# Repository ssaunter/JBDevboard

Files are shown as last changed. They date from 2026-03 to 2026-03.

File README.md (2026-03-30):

# JBDevboard
A custom RP2040 dev board utilizing a NCP1117 LDO. This project is a modified version of the RP2040 devboard project by [Kai Pereira](https://github.com/KaiPereira/build-a-devboard), which has served as a great resource for learning about devboard production. This board is essentially a clone of a Raspberry Pi RP2040 board.

Here is a look at the current build:

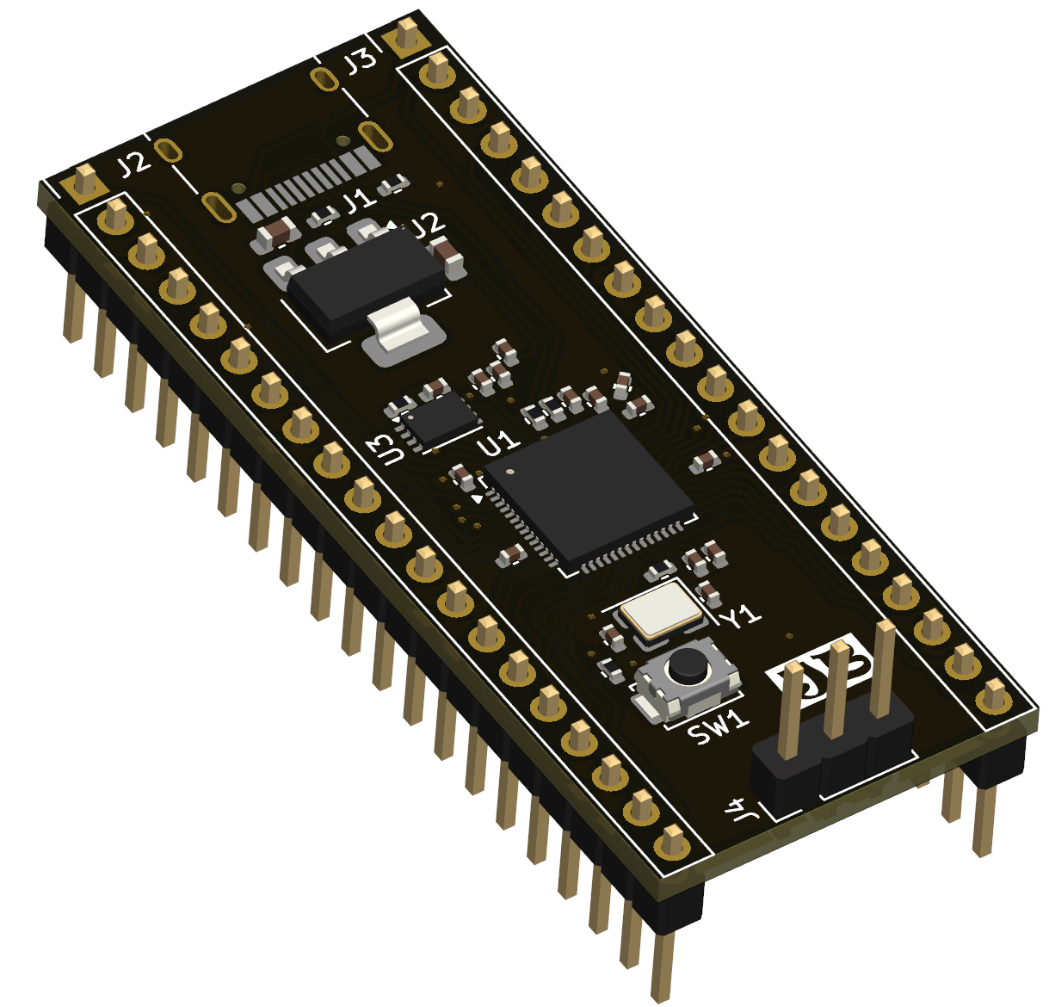
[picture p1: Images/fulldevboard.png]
First Design


The large IC near the back of the board, labeled U2, is the NCP1117. It is capable of providing an output current of 1.0 A, which is an upgrade from the LDOs in the tutorial, which has a max output current of 250 mA.

Here's the schematic:
---

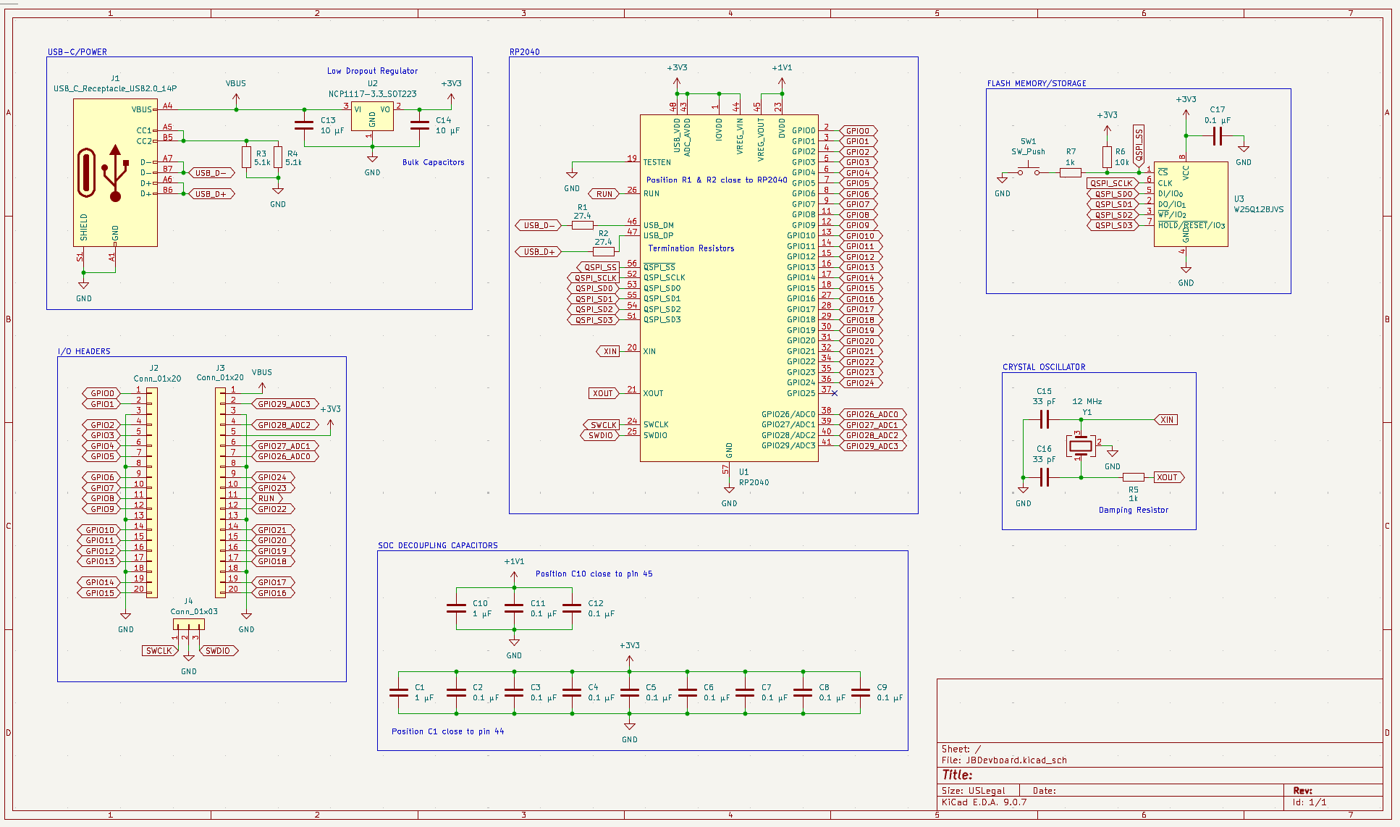
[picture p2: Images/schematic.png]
Schematic Design


And here's what the trace layers look like:
---

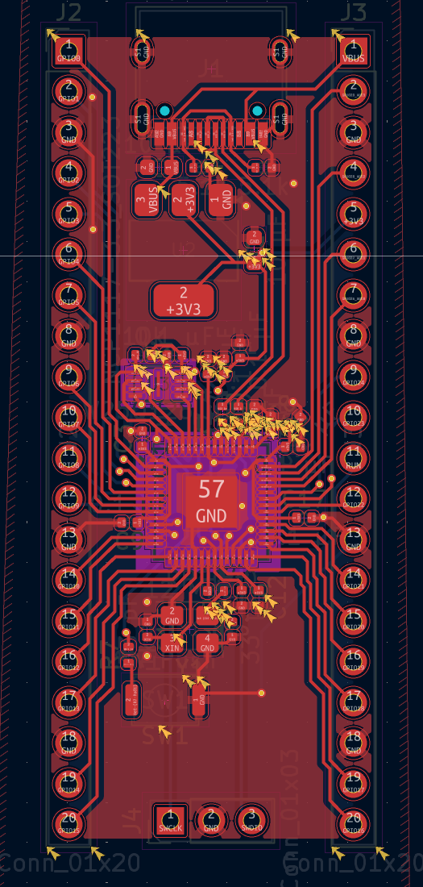
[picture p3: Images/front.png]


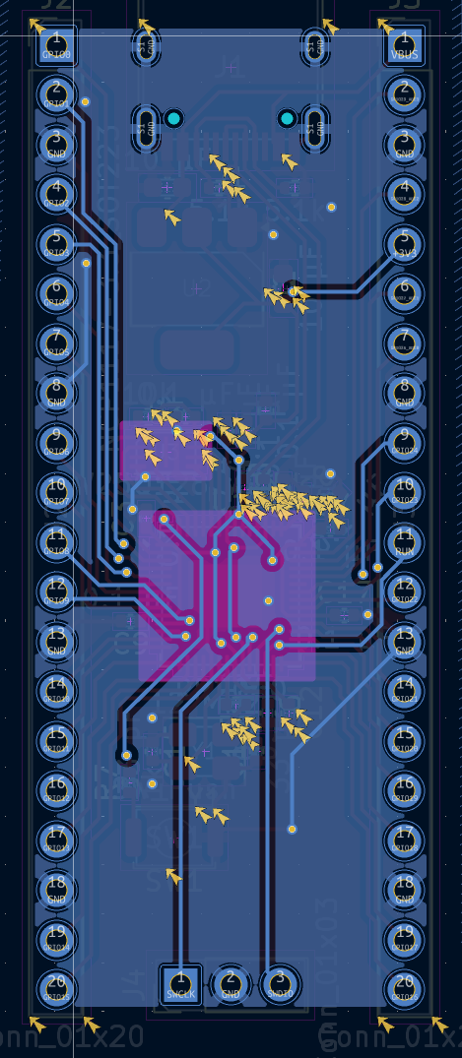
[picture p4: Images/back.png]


---
### Bill of Materials
---

| Part | Quantity | Price Per | Link | 
| :--- | :---: | :---: | :--- |
| **RP2040** | 1 | $0.70 | [DigiKey](https://www.digikey.com/short/ndb2782v) |
| **NCP1117** | 1 | $0.37 | [DigiKey](https://www.digikey.com/short/5j4t47bt) |
| **USB-C Recepticle** | 1 | $0.47 | [DigiKey](https://www.digikey.com/short/z2dbcnt0) |
| **W25Q128JVEIM TR** | 1 | $2.31 | [DigiKey](https://www.digikey.com/short/mfqznn09) |
| **12 Mhz Xtal Osc** | 1 | $1.35 | [DigiKey](https://www.digikey.com/short/h02qvddd) |
| **1x20 Header** | 2 | $0.50 |[DigiKey](https://www.digikey.com/short/dqz7fj2b) |
| **1x3 Header** | 1 | $0.17 | [DigiKey](https://www.digikey.com/short/td5n0hbf) |
| **5.1k R 0402** | 2 | $0.10 |[DigiKey](https://www.digikey.com/short/c9z4njr9) |
| **27.4 R 0402** | 2 | $0.10 |[DigiKey](https://www.digikey.com/short/pqdzv9nf) |
| **1k R 0402** | 2 | $0.10 | [DigiKey](https://www.digikey.com/short/ptpr3b5v) |
| **10k R 0402** | 1 | $0.10 |[DigiKey](https://www.digikey.com/short/1bqf9rrt) |
| **0.1uF C 0402** | 11 | $0.03 |[DigiKey](https://www.digikey.com/short/prnwd7b4) |
| **1uF C 0402** | 1 | $0.08 | [DigiKey](https://www.digikey.com/short/bh2hq3n5) |
| **33pF C 0402** | 2 | $0.10 |[DigiKey](https://www.digikey.com/short/87qt971h) |
| **10uF C 0603** | 2 | $0.47 |[DigiKey](https://www.digikey.com/short/22nm5zq0) |
| **Push Button** | 1 | $0.41 | [DigiKey](https://www.digikey.com/short/8bz14998) |
| **PCB** | 1 | $2.10 | [JCLPCB](https://jlcpcb.com/) |
| **PCB Stencil** | 1 | $7.11 | [JCLPCB](https://jlcpcb.com/) |
| **JLCPCB Tax + Shipping** |  | ~$20.31 | |
| **DigiKey Tax + Shipping** |  | ~$8.56 | 
| **TOTAL** |  | $46.12 |

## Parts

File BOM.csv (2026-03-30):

Part | Quantity | Price Per | Link
RP2040 | 1 | $0.70 | https://www.digikey.com/short/ndb2782v
NCP1117 | 1 | $0.37 | https://www.digikey.com/short/5j4t47bt
USB-C Recepticle | 1 | $0.47 | https://www.digikey.com/short/z2dbcnt0
W25Q128JVEIM TR | 1 | $2.31 | https://www.digikey.com/short/mfqznn09
12 Mhz Xtal Osc | 1 | $1.35 | https://www.digikey.com/short/h02qvddd
1x20 Header | 2 | $0.50 | https://www.digikey.com/short/dqz7fj2b
1x3 Header | 1 | $0.17 | https://www.digikey.com/short/td5n0hbf
5.1k R 0402 | 2 | $0.10 | https://www.digikey.com/short/c9z4njr9
27.4 R 0402 | 2 | $0.10 | https://www.digikey.com/short/pqdzv9nf
1k R 0402 | 2 | $0.10 | https://www.digikey.com/short/ptpr3b5v
10k R 0402 | 1 | $0.10 | https://www.digikey.com/short/1bqf9rrt
0.1uF C 0402 | 11 | $0.03 | https://www.digikey.com/short/prnwd7b4
1uF C 0402 | 1 | $0.08 | https://www.digikey.com/short/bh2hq3n5
33pF C 0402 | 2 | $0.10 | https://www.digikey.com/short/87qt971h
10uF C 0603 | 2 | $0.47 | https://www.digikey.com/short/22nm5zq0
Push Button | 1 | $0.41 | https://www.digikey.com/short/8bz14998
PCB | 1 | $2.10 | https://jlcpcb.com/
PCB Stencil | 1 | $7.11 | https://jlcpcb.com/
JLCPCB Tax + Shipping |  | ~$20.31
DigiKey Tax + Shipping |  | ~$8.56
TOTAL |  | $46.12

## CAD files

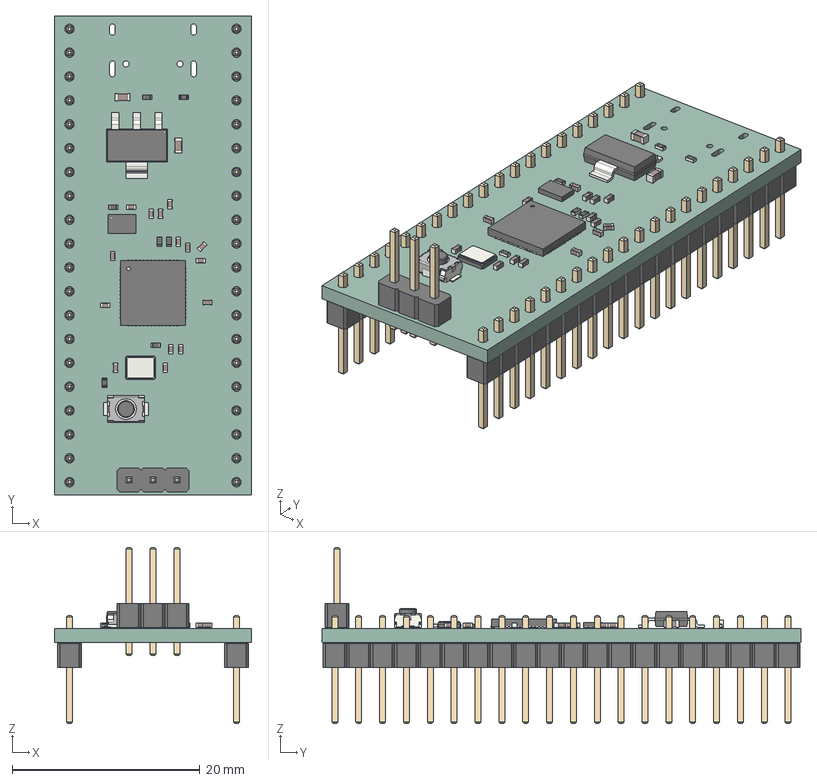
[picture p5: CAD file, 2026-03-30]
cad/JBDevboard.step
21.0 x 51.0 x 18.8 mm
R_0402_1005Metric x 7
PinHeader_1x03_P2.54mm_Vertical
C_0402_1005Metric x 15
SW_Push_SPST_NO_Alps_SKRK
C_0603_1608Metric x 2
QFN-56-1EP_7x7mm_P0.4mm_EP3.2x3.2mm
SOT-223
PinHeader_1x20_P2.54mm_Vertical x 2
Crystal_SMD_3225-4Pin_3.2x2.5mm
Winbond_USON-8-1EP_3x2mm_P0.5mm_EP0.2x1.6mm
JBDevboard_PCB

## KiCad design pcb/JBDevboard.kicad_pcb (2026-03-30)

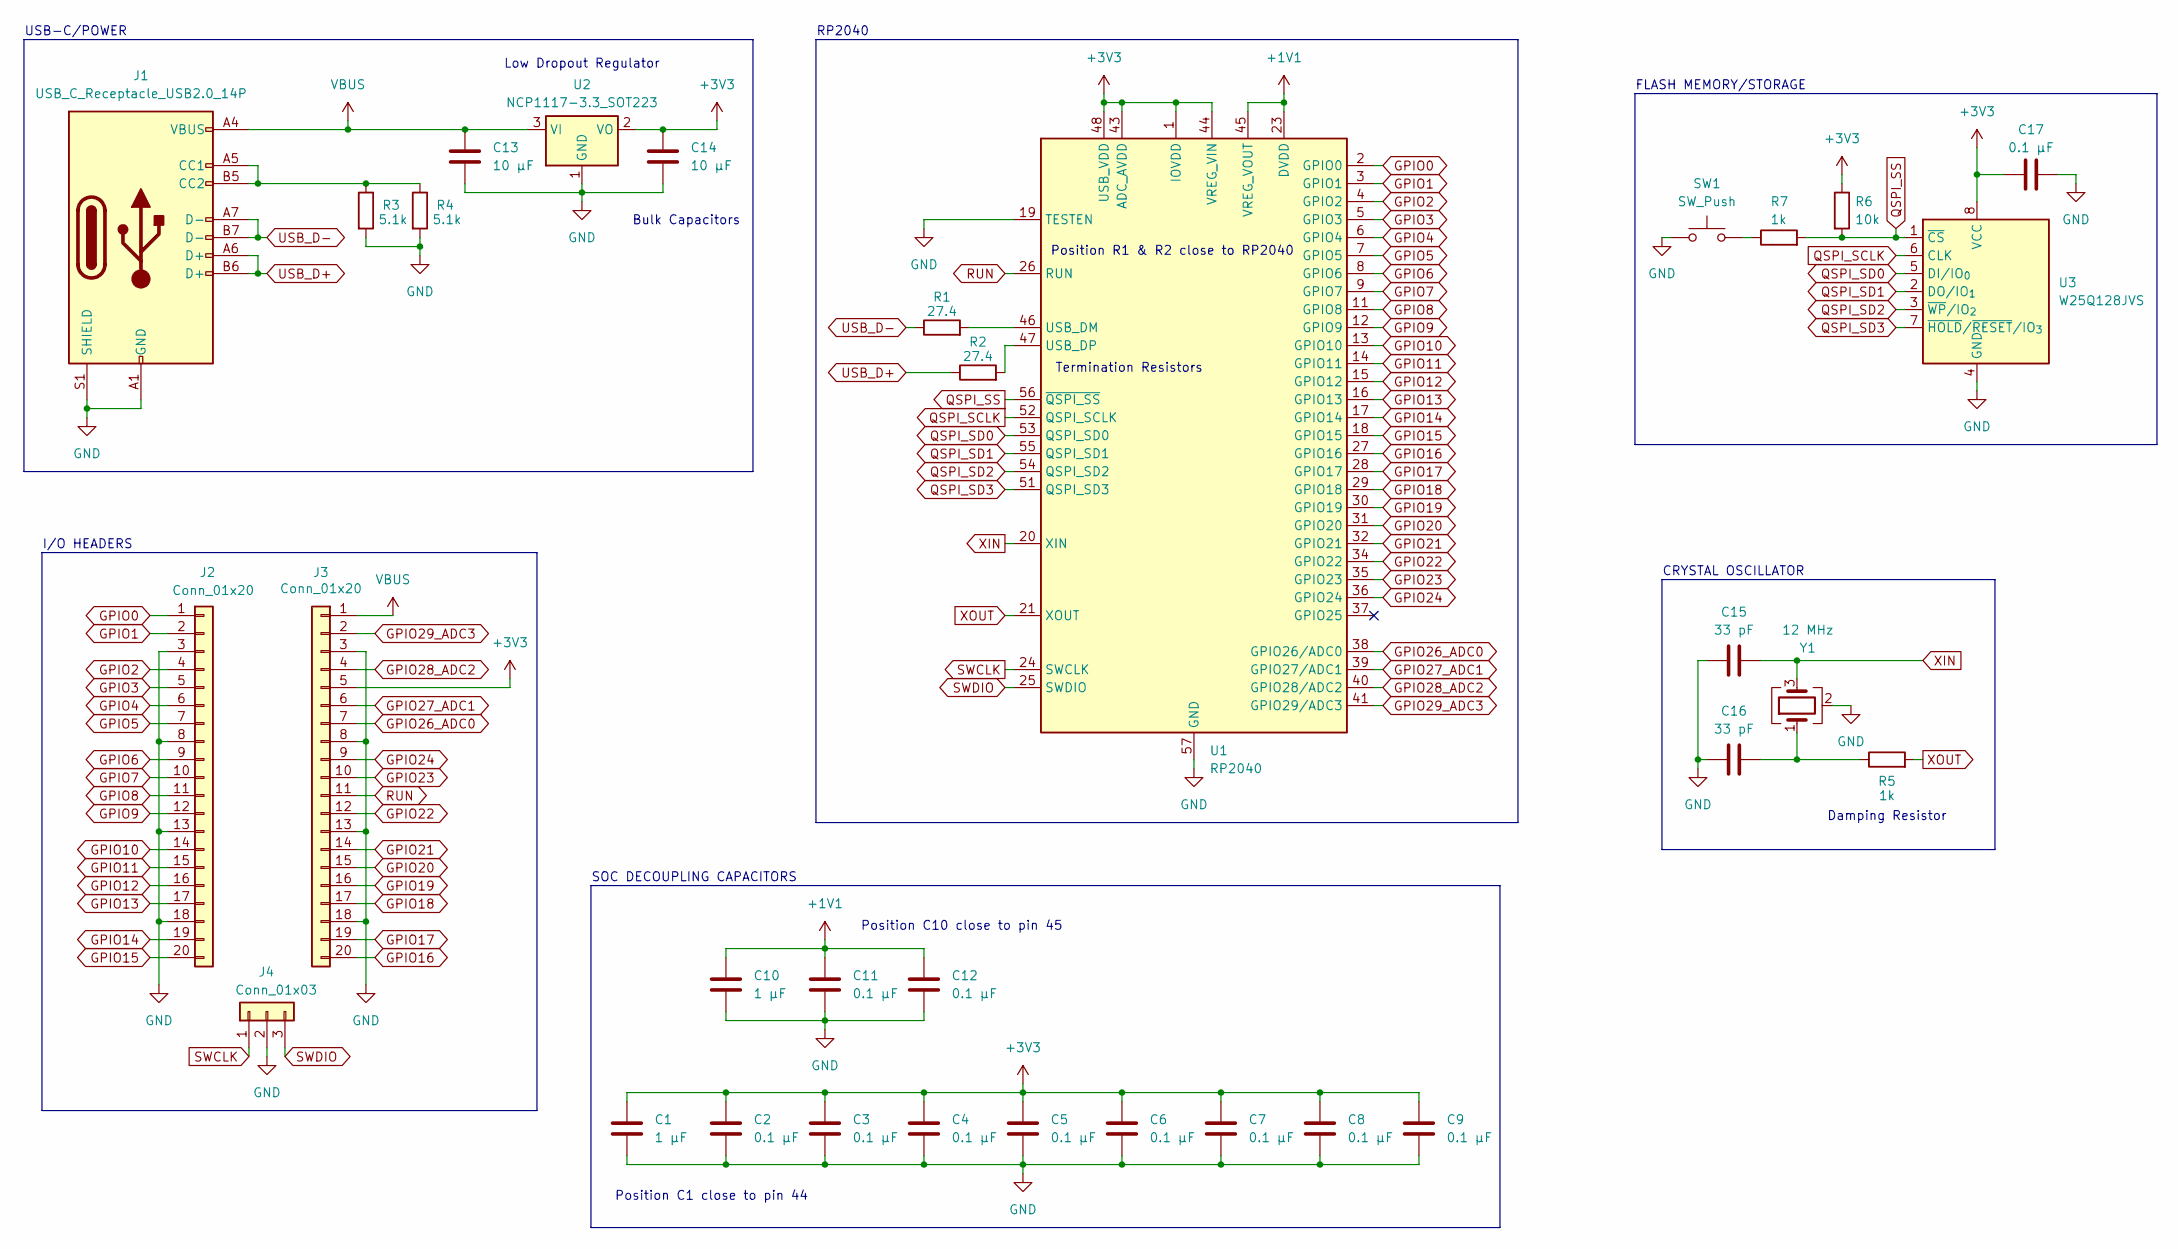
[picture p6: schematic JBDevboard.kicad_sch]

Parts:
C1, C10: 1 μF; C_0402_1005Metric
C2, C3, C4, C5, C6, C7, C8, C9, C11, C12, C17: 0.1 μF; C_0402_1005Metric
C13, C14: 10 μF; C_0603_1608Metric
C15, C16: 33 pF; C_0402_1005Metric
J1: USB_C_Receptacle_USB2.0_14P; USB_C_Receptacle_HRO_TYPE-C-31-M-12
J2, J3: Conn_01x20; PinHeader_1x20_P2.54mm_Vertical
J4: Conn_01x03; PinHeader_1x03_P2.54mm_Vertical
R1, R2: 27.4; R_0402_1005Metric
R3, R4: 5.1k; R_0402_1005Metric
R5, R7: 1k; R_0402_1005Metric
R6: 10k; R_0402_1005Metric
SW1: SW_Push; SW_Push_SPST_NO_Alps_SKRK
U1: RP2040; QFN-56-1EP_7x7mm_P0.4mm_EP3.2x3.2mm
U2: NCP1117-3.3_SOT223; SOT-223-3_TabPin2
U3: W25Q128JVS; Winbond_USON-8-1EP_3x2mm_P0.5mm_EP0.2x1.6mm
Y1: 12 MHz; Crystal_SMD_3225-4Pin_3.2x2.5mm

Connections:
+1V1: C10.1, C11.1, C12.1, U1.23 (DVDD), U1.45 (VREG_VOUT), U1.50 (DVDD)
+3V3: C1.1, C2.1, C3.1, C4.1, C5.1, C6.1, C7.1, C8.1, C9.1, C14.1, C17.1, J3.5, R6.1, U1.1 (IOVDD), U1.10 (IOVDD), U1.22 (IOVDD), U1.33 (IOVDD), U1.42 (IOVDD), U1.43 (ADC_AVDD), U1.44 (VREG_VIN), U1.48 (USB_VDD), U1.49 (IOVDD), U2.2 (VO), U3.8 (VCC)
GND: C1.2, C2.2, C3.2, C4.2, C5.2, C6.2, C7.2, C8.2, C9.2, C10.2, C11.2, C12.2, C13.2, C14.2, C15.1, C16.1, C17.2, J1.A1 (GND), J1.A12 (GND), J1.B1 (GND), J1.B12 (GND), J1.S1 (SHIELD), J2.3, J2.8, J2.13, J2.18, J3.3, J3.8, J3.13, J3.18, J4.2, R3.2, R4.2, SW1.1, U1.19 (TESTEN), U1.57 (GND), U2.1 (GND), U3.4 (GND), Y1.2 (G), Y1.4 (G)
GPIO0: J2.1, U1.2 (GPIO0)
GPIO1: J2.2, U1.3 (GPIO1)
GPIO2: J2.4, U1.4 (GPIO2)
GPIO3: J2.5, U1.5 (GPIO3)
GPIO4: J2.6, U1.6 (GPIO4)
GPIO5: J2.7, U1.7 (GPIO5)
GPIO6: J2.9, U1.8 (GPIO6)
GPIO7: J2.10, U1.9 (GPIO7)
GPIO8: J2.11, U1.11 (GPIO8)
GPIO9: J2.12, U1.12 (GPIO9)
GPIO10: J2.14, U1.13 (GPIO10)
GPIO11: J2.15, U1.14 (GPIO11)
GPIO12: J2.16, U1.15 (GPIO12)
GPIO13: J2.17, U1.16 (GPIO13)
GPIO14: J2.19, U1.17 (GPIO14)
GPIO15: J2.20, U1.18 (GPIO15)
GPIO16: J3.20, U1.27 (GPIO16)
GPIO17: J3.19, U1.28 (GPIO17)
GPIO18: J3.17, U1.29 (GPIO18)
GPIO19: J3.16, U1.30 (GPIO19)
GPIO20: J3.15, U1.31 (GPIO20)
GPIO21: J3.14, U1.32 (GPIO21)
GPIO22: J3.12, U1.34 (GPIO22)
GPIO23: J3.10, U1.35 (GPIO23)
GPIO24: J3.9, U1.36 (GPIO24)
GPIO26_ADC0: J3.7, U1.38 (GPIO26/ADC0)
GPIO27_ADC1: J3.6, U1.39 (GPIO27/ADC1)
GPIO28_ADC2: J3.4, U1.40 (GPIO28/ADC2)
GPIO29_ADC3: J3.2, U1.41 (GPIO29/ADC3)
unnamed: C16.2, R5.1, Y1.1
unnamed: J1.A5 (CC1), J1.B5 (CC2), R3.1, R4.1
unnamed: R7.1, SW1.2
unnamed: R1.2, U1.46 (USB_DM)
unnamed: R2.2, U1.47 (USB_DP)
QSPI_SCLK: U1.52 (QSPI_SCLK), U3.6 (CLK)
QSPI_SD0: U1.53 (QSPI_SD0), U3.5 (DI/IO_{0})
QSPI_SD1: U1.55 (QSPI_SD1), U3.2 (DO/IO_{1})
QSPI_SD2: U1.54 (QSPI_SD2), U3.3 (~WP/IO_{2})
QSPI_SD3: U1.51 (QSPI_SD3), U3.7 (~HOLD/~RESET/IO_{3})
QSPI_SS: R6.2, R7.2, U1.56 (~QSPI_SS), U3.1 (~CS)
RUN: J3.11, U1.26 (RUN)
SWCLK: J4.1, U1.24 (SWCLK)
SWDIO: J4.3, U1.25 (SWDIO)
USB_D+: J1.A6 (D+), J1.B6 (D+), R2.1
USB_D-: J1.A7 (D-), J1.B7 (D-), R1.1
VBUS: C13.1, J1.A4 (VBUS), J1.A9 (VBUS), J1.B4 (VBUS), J1.B9 (VBUS), J3.1, U2.3 (VI)
XIN: C15.2, U1.20 (XIN), Y1.3
XOUT: R5.2, U1.21 (XOUT)

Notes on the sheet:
Bulk Capacitors
Termination Resistors
Position R1 & R2 close to RP2040
I/O HEADERS
Damping Resistor
Position C1 close to pin 44
Position C10 close to pin 45
FLASH MEMORY/STORAGE
CRYSTAL OSCILLATOR
Low Dropout Regulator
USB-C/POWER
SOC DECOUPLING CAPACITORS
RP2040

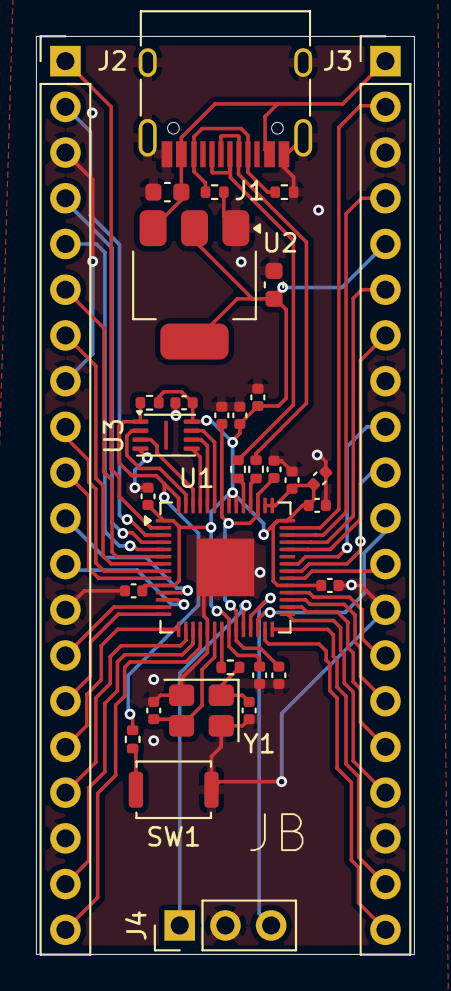
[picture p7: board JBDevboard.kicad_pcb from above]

Board: 2 copper layers, 21.0 x 51.0 mm, 33 parts (0 on the bottom side), 51 nets.

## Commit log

2026-03-30 main update
    first addition of files
    [BOM.csv, JBDevboard.kicad_pcb, JBDevboard.kicad_sch]
2026-03-30 added cad file
    [JBDevboard.step]
2026-03-30 updated bom
    changed some links and accounted for jlcpcb shipping stencil
    [BOM.csv]
